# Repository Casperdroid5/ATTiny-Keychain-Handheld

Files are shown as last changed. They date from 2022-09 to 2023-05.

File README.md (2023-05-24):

# ATTiny Keychain Handheld

The ATTiny Keychain Handheld is an open-source project aimed at creating a compact and portable handheld device using the ATTiny microcontroller. This project provides a platform for hobbyists and electronics enthusiasts to build their own handheld device for various purposes such as gaming, basic applications, or custom projects.

## Features

- Compact and portable design
- ATTiny microcontroller
- OLED display
- User input
- Programmable
- Open-source

## Usage

To use the ATTiny Keychain Handheld, follow these steps:

1. Clone or download the project repository from [GitHub](https://github.com/Casperdroid5/ATTiny-Keychain-Handheld).
2. Gather the necessary components and tools required for building the handheld device.
3. Assemble the device following the step-by-step instructions provided in the documentation.
4. Upload the firmware code to the ATTiny microcontroller using the provided programming instructions.
5. Customize the device as desired by modifying the firmware code or the design files for the enclosure.

## Documentation

Detailed documentation and guides on how to build and customize the handheld device can be found in the [Documentation](https://github.com/Casperdroid5/ATTiny-Keychain-Handheld/tree/main/Documentation) directory of the project repository. The documentation includes component lists, PCB design and circuit diagrams.

## Contributing

Contributions to the ATTiny Keychain Handheld project are welcome. If you find any issues, have suggestions for improvements, or want to contribute new features, please refer to the [Contributing](https://github.com/Casperdroid5/ATTiny-Keychain-Handheld/tree/main/Contributing) directory in the project repository.

## License

The ATTiny Keychain Handheld project is released under the [MIT License](https://github.com/Casperdroid5/ATTiny-Keychain-Handheld/blob/main/LICENSE).

## Conclusion

The ATTiny Keychain Handheld project offers an exciting opportunity for electronics enthusiasts and hobbyists to build their own portable handheld device. With its compact design, ATTiny microcontroller, and open-source nature, the project provides a versatile platform for creating various applications and games. Whether you are a beginner or an experienced developer, this project encourages exploration and customization.

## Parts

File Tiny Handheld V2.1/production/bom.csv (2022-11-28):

Designator | Footprint | Quantity | Value | LCSC Part #
5V | TestPoint_Pad_1.0x1.0mm | 1 | 5V
BT1 | BatteryHolder_Keystone_3002_1x2032 | 1 | Battery_Cell
C1 | C_1206_3216Metric_Pad1.33x1.80mm_HandSolder | 1 | 1uF 16V
C2 | C_1206_3216Metric_Pad1.33x1.80mm_HandSolder | 1 | 1uF
C3 | C_1206_3216Metric_Pad1.33x1.80mm_HandSolder | 1 | 47uF
C4 | C_1206_3216Metric_Pad1.33x1.80mm_HandSolder | 1 | 100nF
C6 | C_1206_3216Metric_Pad1.33x1.80mm_HandSolder | 1 | 2.2uF 16V
D1, D2 | LED_1206_3216Metric_Pad1.42x1.75mm_HandSolder | 2 | LED
GND | TestPoint_Pad_1.0x1.0mm | 1 | GND
H1 | MountingHole_3.2mm_M3 | 1 | MountingHole
IC1 | SOT-23-6_Handsoldering | 1 | BQ21040DBVR
J1 | PinSocket_1x06_P2.54mm_Vertical | 1 | VDisplay/prog1
J2 | PinSocket_1x06_P2.54mm_Vertical | 1 | HDisplay/prog
J3 | TYPE-C-31-M-17_handsolder | 1 | USB_C_Receptacle_USB2.0
JP1, JP2, JP3 | SolderJumper-3_P1.3mm_Open_RoundedPad1.0x1.5mm_NumberLabels | 3 | SolderJumper_3_Bridged123
LS1 | XDCR_KSSGK4B16-20 | 1 | KSSGK4B16-20
R1, R4 | R_1206_3216Metric_Pad1.30x1.75mm_HandSolder | 2 | 88k
R10 | R_1206_3216Metric_Pad1.30x1.75mm_HandSolder | 1 | 10k
R11, R12 | R_1206_3216Metric_Pad1.30x1.75mm_HandSolder | 2 | 4k7
R13, R14 | R_1206_3216Metric_Pad1.30x1.75mm_HandSolder | 2 | 5k1
R15 | R_1206_3216Metric_Pad1.30x1.75mm_HandSolder | 1 | 10k NTC
R16, R8 | R_1206_3216Metric_Pad1.30x1.75mm_HandSolder | 2 | 470
R2, R6 | R_1206_3216Metric_Pad1.30x1.75mm_HandSolder | 2 | 22k
R3, R5, R7 | R_1206_3216Metric_Pad1.30x1.75mm_HandSolder | 3 | 33k
R9 | R_1206_3216Metric_Pad1.30x1.75mm_HandSolder | 1 | 11k
S1 | SW_SPST_TL3305B | 1 | MOMENTARY-SWITCH-SPST-2-SMD-5.2MM
S2 | 5 way button (joystick) | 1 | JOYSTICK_MINI
S3, S4 | SW_JS202011SCQN | 2 | JS202011SCQN
U1 | DIP781W56P254L950H533Q8N | 1 | ATtiny85-20P
U2 | SOIC-8W_5.3x5.3mm_P1.27mm | 1 | ATtiny85-20S
en-charge | SolderJumper-2_P1.3mm_Open_RoundedPad1.0x1.5mm | 1 | Jumper_2_Open

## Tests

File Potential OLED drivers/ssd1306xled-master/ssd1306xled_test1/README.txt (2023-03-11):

TESTING - This is a testing project for the library.

To build the project, type:
	$ make

To upload the binary into the microcontroller, type:
	$ make program

Alternatively, to upload the binary, type:
	$ avrdude -c usbasp -p t85 -U flash:w:"main.hex":a

To clean up files left out from previous builds, type:
   $ make clean

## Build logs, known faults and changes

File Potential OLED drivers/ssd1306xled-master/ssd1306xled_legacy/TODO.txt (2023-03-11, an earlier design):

TODO

2019-04-27 (nb)

- Fix library (probably the init seq.) to work with SSD1315 also. (DONE)

2018-12-26 (nb)

- Move font .h files to the app space, i.e. not in the library folder.
- Separate SSD1306xLEDfx library for the more complex functions such as drawings.	(DONE)
- Separate SSD1306xLEDtx library for the more complex functions such as printing chars and strings.	(DONE)
- Extract the I2C function as a separate library.
- Update makefile to the newer style, like it is in the other projects.	(DONE)
- Use the NUM2STR library from TinyAVRLib project.	(DONE)
- Remove the "_cn" modules - no longer used and developed.	(DONE)

2016, 2017

- Print decimal numbers.	(DONE)
- Short vertical line.
- Implement power saving modes for the display.

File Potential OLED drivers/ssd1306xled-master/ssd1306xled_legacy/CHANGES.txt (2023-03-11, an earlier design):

CHANGES

2019-04-27 (nb)

Code optimizations in ssd1306xledtx for speed and size.

Testing scripts updated and tested.

Updated ssd1306_init_sequence, fixes and more, compatibility with SSD1315.

2019-02-10 (nb)

Testing scripts updated and tested.

Some refactoring/renaming, minor fixes, optimizations, removed unused functions.
- Some refactoring (renaming). Minor fixes.
- Code optimizations for size and speed.
- Removed unused functions.

2019-02-03 (nb)

Added "extern" functions where needed.

FIX: used wrong function - *_start/stop instead of *data_start/stop.

2019-01-27 (nb)

Minor source code reformatting.

Some functions moved to the new internal library - I2CSW - I2C Simple Writer,, other renamed. Testing scripts updated.

2018-12-26 (nb)

Functions from the ssd1306xledtx module now have the ssd1306tx_ prefix, names changed a little. Implemented ssd1306tx_init function.

Moved to a new ssd1306xledtx module, function to work with images.

Moved to a new ssd1306xledfx module, function to work with text.

Updated testing scripts. Source code maintenance. Updated TODO list.

Removed unused modules - local copy of "num2str", "ssd1306xled_cn" and "ssd1306xled_test_cn".

Source code maintenance. Changes in the texts.

2018-05-24 (nb)

Source code reorganizing, reformatting. Removed unused. Some optimizations.

Added new ssd1306xled_text1 module for testing text output.

Improved fonts handling. Moved ssd1306_string_font8x16xy to main library.

Added new ssd1306xled_text2 testing script.

Removed unused ssd1306xled8x16 files.

Switched to using the num2str from the tinyavrlib.

Added new ssd1306xled_nums1 testing script.

Added new ssd1306xled_imgs1 testing script.

Added new ssd1306_byte function that writes one vertical byte on the screen.

Updated ssd1306xled_test1 script to show simple tests.

Fixed bug in the ssd1306_byte function.

2018-05-23 (nb)

Added more comments in the source code.

Remove unused cpufreq.h file. More comments in the source code. Updated copyright and related info.

Improved Makefile. More comments in the source code. Updated copyright and related info.

2016-05-01 (nb)

Added support for, and tested to work with, 8 MHz CPU clock. Other small fixes.

- Added support for, and tested to work with, 8 MHz CPU clock. Using CPUFREQ.
- Replaced "while (1)" with "for (;;)".

2016-05-01 (nb)

Renamed function names - for clarity, added new. Improved testing script.

- Refactoring: renamed ssd1306_fillp to ssd1306_fill2; ssd1306_char_f8x16 to ssd1306_string_font8x16xy.
- Added new: ssd1306_fill4 function; ssd1306_clear macro.
- Improved testing script.

2016-05-01 (nb)

Renamed ssd1306xled_test to ssd1306xled_test1.

2016-05-01 (nb)

Fixed Makefile. Other small changes.

- Fixed Makefile.
- Updated texts, fixed typos.

2016-04-29 (nb)

Updated to the latest NUM2STR. Other small updated and fixes.

- Updated to the latest NUM2STR.
- Removed old unused code.
- Updated text files. Fixed typos.

2015-09-26 (nb)

Added new functions and definitions. Updated testing app. Other small fixes.

- Added macro definitions for new ssd1306_char, ssd1306_string, ssd1306_numdec, ssd1306_numdecp functions.
- Added new ssd1306_fillp, ssd1306_fill functions.
- Removed old and unused code.
- Updated and improved testing app.
- Fixes in texts and comments.

2015-01-17 (nb)

Added support for printing decimal numbers.

- Added support for printing decimal numbers with the "num2str" library. New functions: ssd1306_numdec_font6x8, ssd1306_numdecp_font6x8.
- Minor updates in the text files.

2015-01-13 (nb)

Updated README file - added folders and files layout.

2015-01-12 (nb)

Added MIT License info, added LICENSE.txt file. Added licensing info to the source code file.

2015-01-12 (nb)

Updated RESEARCH and TODO files.

2015-01-10 (nb)

Fixed and improved initialization. New and improved printing of text. Updated texts.

- Fixed initialization commands.
- Implemented ssd1306_init more efficiently.
- New functions ssd1306_send_command_start, ssd1306_send_command_stop.
- Improved ssd1306_setpos, more efficient.
- Reimplemented function ssd1306_char_f6x8 as improved ssd1306_char_font6x8 printing single characters only, added new ssd1306_string_font6x8 for printing strings.
- The font8x16 functions and data moved to another file until properly implemented.
- Added to the Make file ssd1306xled8x16 file.
- Updated testing text displayed on the screen.

2015-01-10 (nb)

Changed default pins for display, now PB0=SCL and PB1=SDA. Source code reformatting, improvements, edited comments.

- Changed default pins for connecting to the display for consistency with the built-in TWI interface, they are now PB0=SCL and PB1=SDA.
- Source code, removed redundant initializations of variables.
- Source code reformatting, edited comments.

2015-01-10 (nb)

Fixed some warnings, variables renamed. The font16x16/Chinese stuff moved to other folders.

- Font variable ssd1306xled_font8X16 renamed to ssd1306xled_font8x16 for consistency. TODO: rename "ssd1306xled_font8x16" file as well.
- Fixed ssd1306_draw_bmp prototype: added "const" to bitmap so it won't generate warning.
- Files related to font 16x16 (Chinese) moved to different folders: font16x16cn.h.
- Functions and other code related to font 16x16 (Chinese) moved to different folders.
- Source code reformatting, edited comments.

2014-10-26 (gs)

Make project compile on gcc-avr - turn static images to consts, and rename include of font16x16cn.h

2014-08-13 (nb)

More files added to the repository.

2014-08-11 (nb)

Files added to the repository.

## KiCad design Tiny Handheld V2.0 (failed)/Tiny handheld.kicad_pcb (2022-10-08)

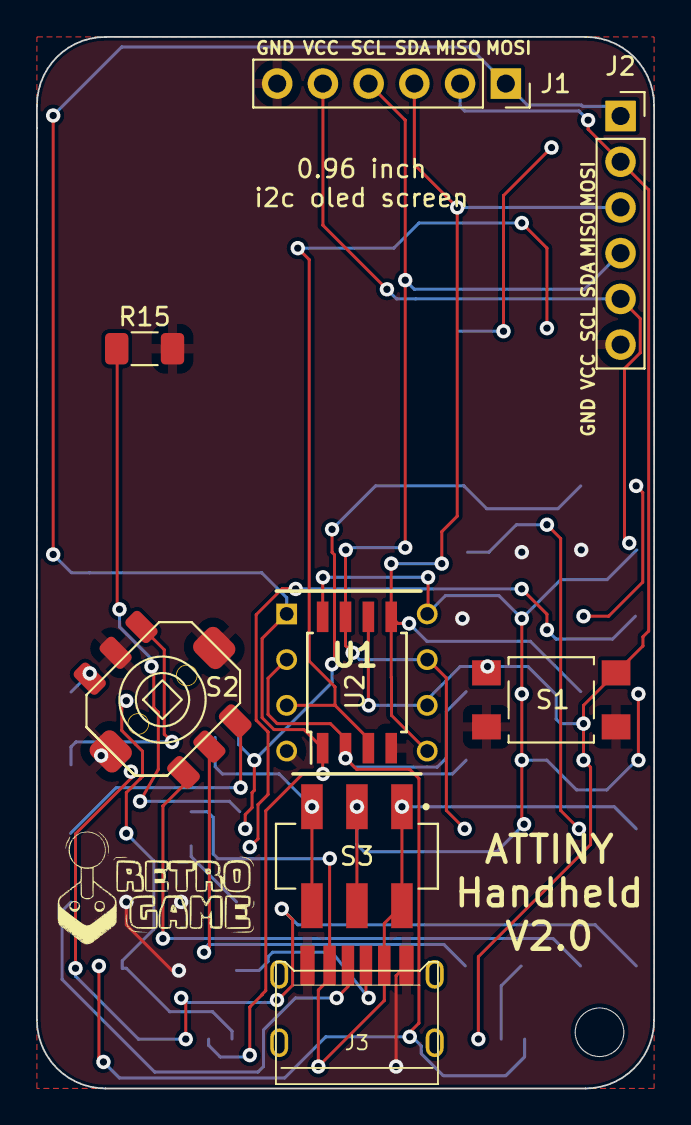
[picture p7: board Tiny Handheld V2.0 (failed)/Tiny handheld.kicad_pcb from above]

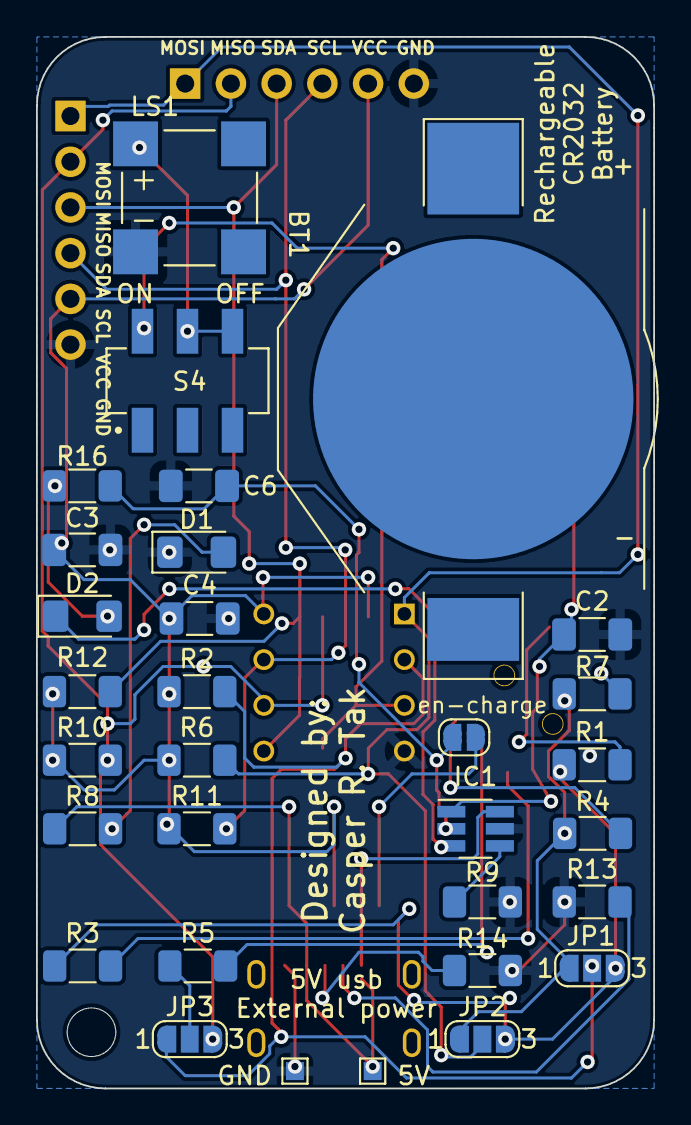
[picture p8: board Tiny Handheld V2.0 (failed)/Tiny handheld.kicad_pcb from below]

Board: 2 copper layers, 34.3 x 58.4 mm, 40 parts (31 on the bottom side), 27 nets.

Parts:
5V: 5V; TestPoint_Pad_1.0x1.0mm
BT1: BATTERY-6.8MM_SMD; BatteryHolder_Keystone_3002_1x2032
C2: 1uF; C_1206_3216Metric_Pad1.33x1.80mm_HandSolder
C3: 47uF; C_1206_3216Metric_Pad1.33x1.80mm_HandSolder
C4: 100nF; C_1206_3216Metric_Pad1.33x1.80mm_HandSolder
C6: 2.2uF 16V; C_1206_3216Metric_Pad1.33x1.80mm_HandSolder
D1, D2: LED; LED_1206_3216Metric_Pad1.42x1.75mm_HandSolder
GND: GND; TestPoint_Pad_1.0x1.0mm
IC1: BQ21040DBVR; SOT-23-6_Handsoldering
J1: VDisplay/prog1; PinSocket_1x06_P2.54mm_Vertical
J2: HDisplay/prog; PinSocket_1x06_P2.54mm_Vertical
J3: USB_C_Receptacle_USB2.0; TYPE-C-31-M-17_handsolder
JP1, JP2, JP3: SolderJumper_3_Bridged123; SolderJumper-3_P1.3mm_Open_RoundedPad1.0x1.5mm_NumberLabels
LS1: KSSGK4B16-20; XDCR_KSSGK4B16-20
R1, R4: 88k; R_1206_3216Metric_Pad1.30x1.75mm_HandSolder
R2, R6: 22k; R_1206_3216Metric_Pad1.30x1.75mm_HandSolder
R3, R5, R7: 33k; R_1206_3216Metric_Pad1.30x1.75mm_HandSolder
R8, R16: 470; R_1206_3216Metric_Pad1.30x1.75mm_HandSolder
R9: 11k; R_1206_3216Metric_Pad1.30x1.75mm_HandSolder
R10: 10k; R_1206_3216Metric_Pad1.30x1.75mm_HandSolder
R11, R12: 4k7; R_1206_3216Metric_Pad1.30x1.75mm_HandSolder
R13, R14: 5k1; R_1206_3216Metric_Pad1.30x1.75mm_HandSolder
R15: 10k NTC; R_1206_3216Metric_Pad1.30x1.75mm_HandSolder
S1: MOMENTARY-SWITCH-SPST-2-SMD-5.2MM; SW_SPST_TL3305B
S2: JOYSTICK_MINI; 5 way button (joystick)
S3, S4: JS202011SCQN; SW_JS202011SCQN
U1: ATtiny85-20P; DIP781W56P254L950H533Q8N
U2: ATtiny85-20S; SOIC-8W_5.3x5.3mm_P1.27mm
en-charge: Jumper_2_Open; SolderJumper-2_P1.3mm_Open_RoundedPad1.0x1.5mm

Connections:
BatOut: S3.3, S3.6, en-charge.2 (B)
ExtVCC: 5V.1, IC1.6 (VIN), J3.A9 (VBUS), J3.B9 (VBUS), R8.1, S3.1, S3.4
GND: C2.2, C3.2, C4.2, C6.2, D1.1 (K), GND.1, IC1.5 (GND), J1.6, J2.6, J3.A12 (GND), J3.B12 (GND), LS1.N, R9.2, R13.1, R14.1, R15.2, S1.1, S1.2, S2.7, S2.8, S2.GND, U1.4 (GND), U2.4 (GND)
unnamed: C2.1, IC1.1 (TS), R15.1
unnamed: C6.1, IC1.2 (OUT), R16.1, en-charge.1 (A)
unnamed: D1.2 (A), R8.2
unnamed: D2.1 (K), IC1.3 (~CHG)
unnamed: D2.2 (A), R16.2
unnamed: IC1.4 (ISET), R9.1
unnamed: J3.A5 (CC1), R13.2
unnamed: J3.B5 (CC2), R14.2
unnamed: JP1.1 (A), JP2.1 (A), R4.1, R7.1
unnamed: JP1.3 (B), JP2.3 (B), R1.1, R3.1
unnamed: JP3.2 (C), R5.1
unnamed: LS1.P, S4.5, S4.6
unnamed: R1.2, S2.D (DOWN)
unnamed: R3.2, S2.A (UP)
unnamed: R4.2, S2.C (LEFT)
unnamed: R5.2, S2.CTR (CENT)
unnamed: R7.2, S2.B (RIGHT)
PB0/SDA/MOSI: J1.3, J2.3, R12.2, U1.5 (AREF/PB0), U2.5 (AREF/PB0)
PB1/MISO: J1.2, J2.2, JP3.3 (B), R10.2, S1.3, S1.4, U1.6 (PB1), U2.6 (PB1)
PB2/SCL/SCK: J1.4, J2.4, R11.2, U1.7 (PB2), U2.7 (PB2)
PB3: JP1.2 (C), JP3.1 (A), R2.2, U1.2 (XTAL1/PB3), U2.2 (XTAL1/PB3)
PB4: S4.4, U1.3 (XTAL2/PB4), U2.3 (XTAL2/PB4)
PB5/RES: J1.1, J2.1, JP2.2 (C), R6.2, U1.1 (~RESET/PB5), U2.1 (~RESET/PB5)
VCC: C3.1, C4.1, J1.5, J2.5, R2.1, R6.1, R10.1, R11.1, R12.1, S3.2, S3.5, U1.8 (VCC), U2.8 (VCC)

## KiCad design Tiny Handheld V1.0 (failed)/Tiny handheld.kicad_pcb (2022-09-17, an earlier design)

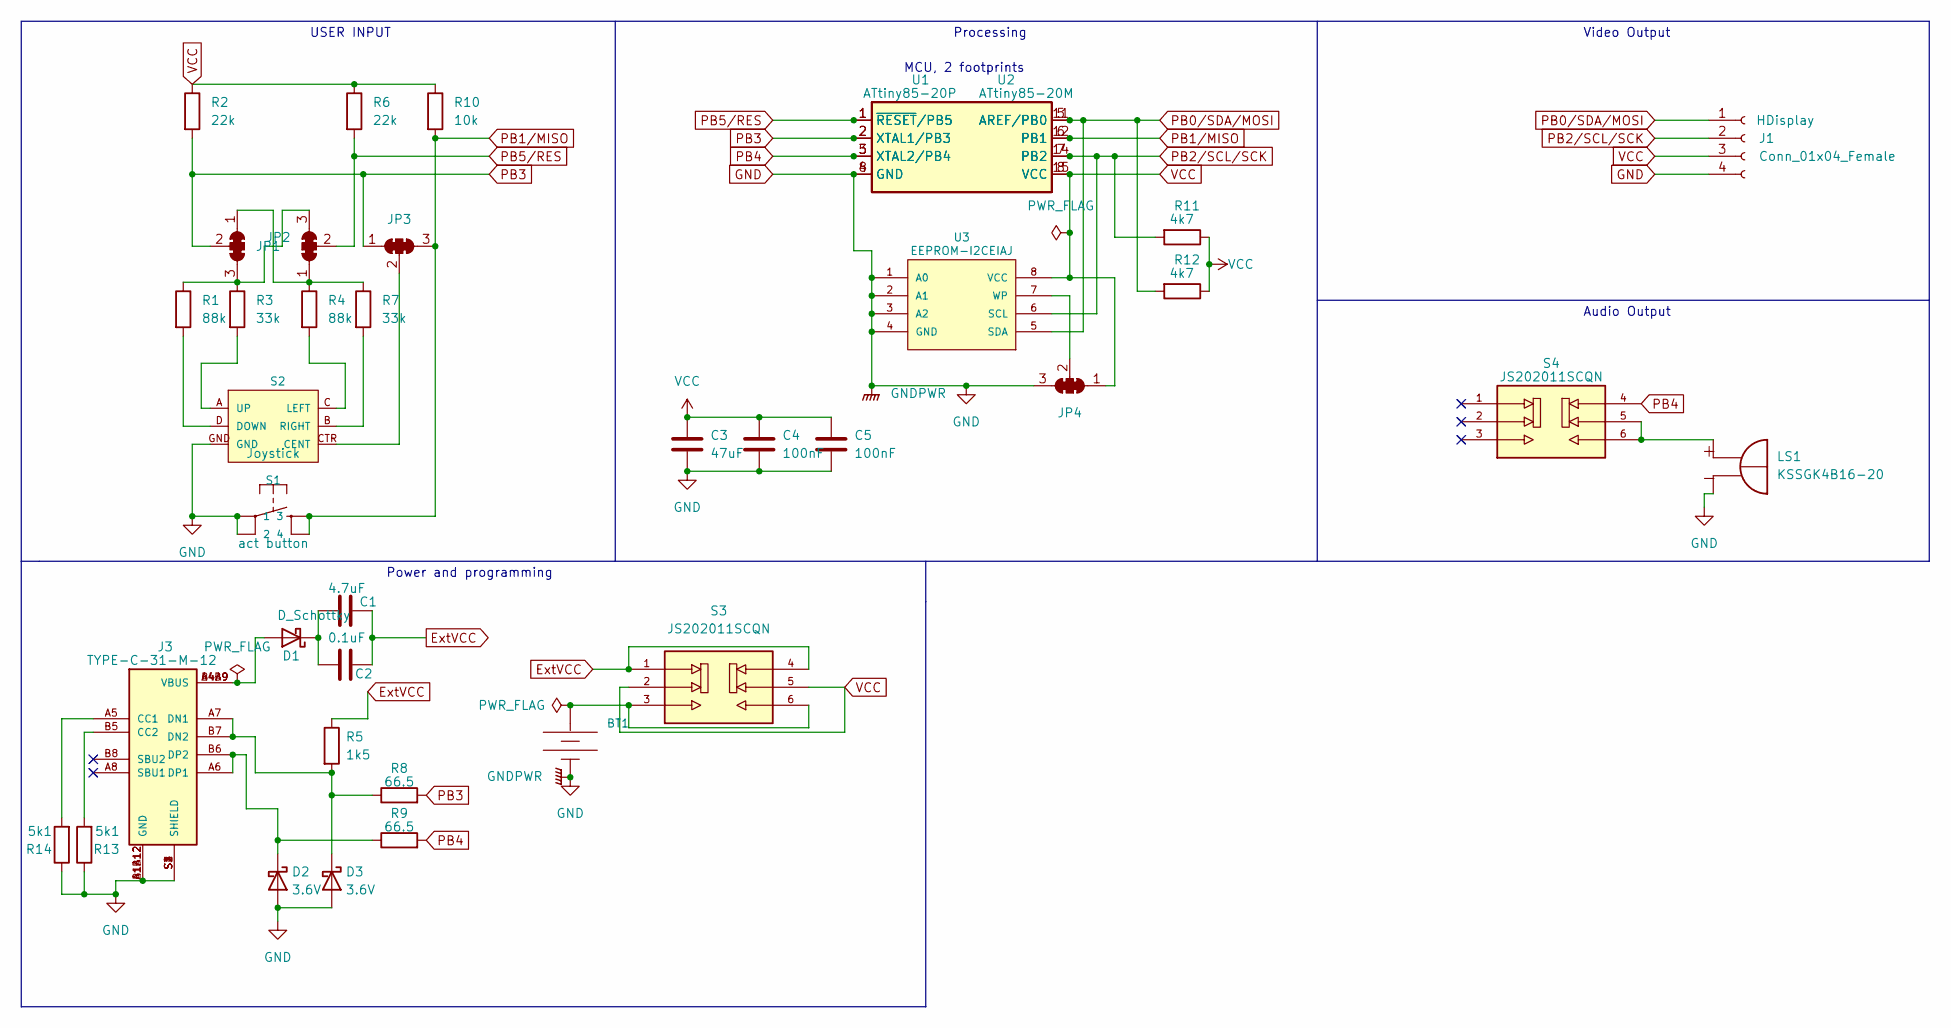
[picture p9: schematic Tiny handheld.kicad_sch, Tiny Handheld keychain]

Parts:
BT1: BATTERY-6.8MM_SMD; BAT_BU2032-1
C1: 4.7uF; C_1206_3216Metric_Pad1.33x1.80mm_HandSolder
C2: 0.1uF; C_1206_3216Metric_Pad1.33x1.80mm_HandSolder
C3: 47uF; C_1206_3216Metric_Pad1.33x1.80mm_HandSolder
C4, C5: 100nF; C_1206_3216Metric_Pad1.33x1.80mm_HandSolder
D1: D_Schottky; D_1210_3225Metric_Pad1.42x2.65mm_HandSolder
D2, D3: 3.6V; D_1210_3225Metric_Pad1.42x2.65mm_HandSolder
J1: Conn_01x04_Female; PinHeader_1x04_P2.54mm_Vertical
J3: TYPE-C-31-M-12; HRO_TYPE-C-31-M-12; PARTREV A
JP1, JP2, JP3, JP4: SolderJumper_3_Bridged123; SolderJumper-3_P1.3mm_Open_RoundedPad1.0x1.5mm_NumberLabels
LS1: KSSGK4B16-20; XDCR_KSSGK4B16-20; PARTREV 1.1
R1, R4: 88k; R_1206_3216Metric_Pad1.30x1.75mm_HandSolder
R2, R6: 22k; R_1206_3216Metric_Pad1.30x1.75mm_HandSolder
R3, R7: 33k; R_1206_3216Metric_Pad1.30x1.75mm_HandSolder
R5: 1k5; R_1206_3216Metric_Pad1.30x1.75mm_HandSolder
R8, R9: 66.5; R_1206_3216Metric_Pad1.30x1.75mm_HandSolder
R10: 10k; R_1206_3216Metric_Pad1.30x1.75mm_HandSolder
R11, R12: 4k7; R_1206_3216Metric_Pad1.30x1.75mm_HandSolder
R13, R14: 5k1; R_1206_3216Metric_Pad1.30x1.75mm_HandSolder
S1: MOMENTARY-SWITCH-SPST-2-SMD-5.2MM; SW_SPST_TL3305B
S2: JOYSTICK_MINI; 5 way button (joystick)
S3, S4: JS202011SCQN; SW_JS202011SCQN; PARTREV 26 May 22
U1: ATtiny85-20P; DIP-8_W7.62mm
U2: ATtiny85-20M; QFN50P400X400X80-21N
U3: EEPROM-I2CEIAJ; SOIC-8_3.9x4.9mm_P1.27mm

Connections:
ExtVCC: C1.1, C2.1, R5.1, S3.1, S3.4
GND: BT1.-, C3.2, C4.2, C5.2, D2.2 (A), D3.2 (A), J1.4, J3.A1B12 (GND), J3.B1A12 (GND), J3.S1 (SHIELD), J3.S2 (SHIELD), J3.S3 (SHIELD), J3.S4 (SHIELD), JP4.3 (B), LS1.N, R13.1, R14.1, S1.1, S1.2, S2.GND, U1.4 (GND), U2.8 (GND), U2.21 (GND), U3.1 (A0), U3.2 (A1), U3.3 (A2), U3.4 (GND)
unnamed: C1.2, C2.2, D1.1 (K)
unnamed: D1.2 (A), J3.A4B9 (VBUS), J3.B4A9 (VBUS)
unnamed: D2.1 (K), J3.A6 (DP1), J3.B6 (DP2), R9.1
unnamed: D3.1 (K), J3.A7 (DN1), J3.B7 (DN2), R5.2, R8.1
unnamed: J3.A5 (CC1), R14.2
unnamed: J3.B5 (CC2), R13.2
unnamed: JP1.1 (A), JP2.1 (A), R4.1, R7.1
unnamed: JP1.3 (B), JP2.3 (B), R1.1, R3.1
unnamed: JP3.2 (C), S2.CTR (CENT)
unnamed: JP4.2 (C), U3.7 (WP)
unnamed: LS1.P, S4.5, S4.6
unnamed: R1.2, S2.D (DOWN)
unnamed: R3.2, S2.A (UP)
unnamed: R4.2, S2.C (LEFT)
unnamed: R7.2, S2.B (RIGHT)
PB0/SDA/MOSI: J1.1, R12.2, U1.5 (AREF/PB0), U2.11 (AREF/PB0), U3.5 (SDA)
PB1/MISO: JP3.3 (B), R10.2, S1.3, S1.4, U1.6 (PB1), U2.12 (PB1)
PB2/SCL/SCK: J1.2, R11.2, U1.7 (PB2), U2.14 (PB2), U3.6 (SCL)
PB3: JP1.2 (C), JP3.1 (A), R2.2, R8.2, U1.2 (XTAL1/PB3), U2.2 (XTAL1/PB3)
PB4: R9.2, S4.4, U1.3 (XTAL2/PB4), U2.5 (XTAL2/PB4)
PB5/RES: JP2.2 (C), R6.2, U1.1 (~RESET/PB5), U2.1 (~RESET/PB5)

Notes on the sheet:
MCU, 2 footprints
Audio Output
Power and programming
USER INPUT
Video Output
Processing

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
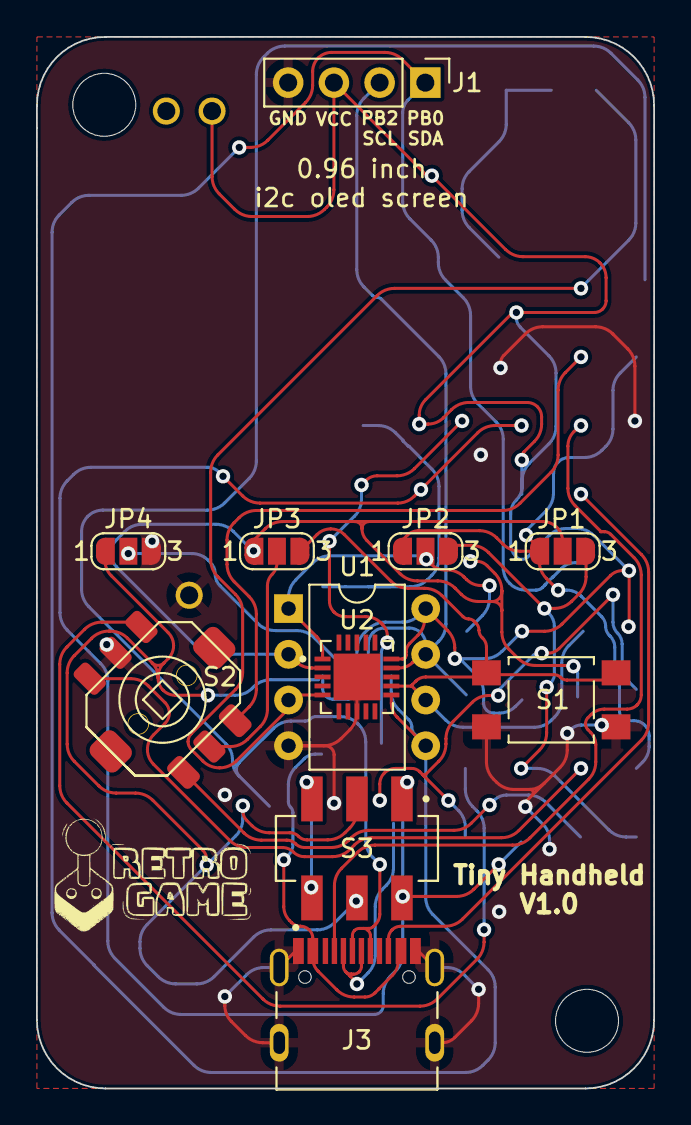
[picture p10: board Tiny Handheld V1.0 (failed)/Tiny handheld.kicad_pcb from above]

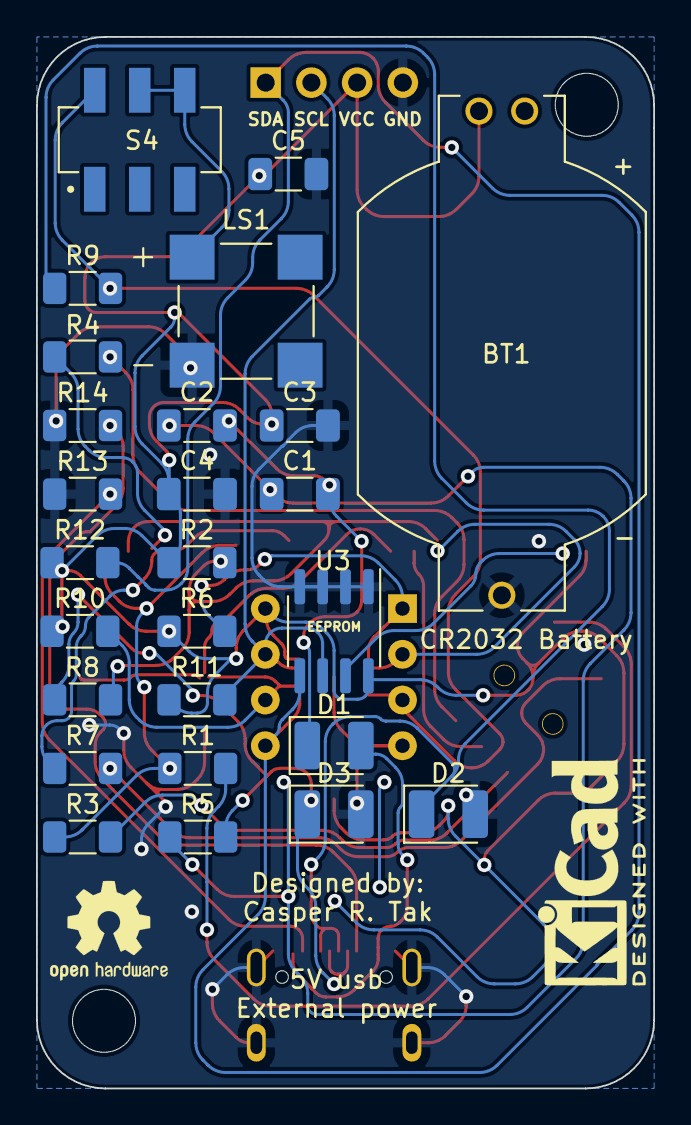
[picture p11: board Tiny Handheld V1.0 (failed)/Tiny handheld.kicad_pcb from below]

Board: 2 copper layers, 34.3 x 58.4 mm, 37 parts (26 on the bottom side), 25 nets.

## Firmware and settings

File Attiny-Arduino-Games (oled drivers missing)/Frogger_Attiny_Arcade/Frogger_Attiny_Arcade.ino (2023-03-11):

/*  2015 / 2016 / 2017
 *  Frogger game by Andy Jackson - Twitter @andyhighnumber
 *  
 *  Special thanks to @senkunmusahi, who created the artwork bitmaps in the game using https://www.riyas.org/2013/12/online-led-matrix-font-generator-with.html
 *  
 *  Inspired by http://webboggles.com/ and includes some code from the #AttinyArcade games on that site
 *  The code that does not fall under the licenses of sources listed below can be used non commercially with attribution.
 *  This software is supplied without warranty of any kind.
 *  
 *  Controls:
 *  On the standard AttinyArcade:
 *  LEFT and RIGHT buttons move the frog across 
 *  BOTH BOTTONS TOGETHER move the frog forwards
 *  
 *  HIGHLY RECOMMENDED:
 *  On custom hardware (see schematic in folder where you found this file) there is an additional button to move frog forward  
 *  
 *  Also, from standby....
 *  Press and hold left button to turn sound on and off
 *  Press and hold left button with the right button held to reset high score
 * 
 *  This sketch is using the screen control and font functions written by Neven Boyanov for the http://tinusaur.wordpress.com/ project
 *  Source code and font files available at: https://bitbucket.org/tinusaur/ssd1306xled
 *  **Note that this highly size-optimised version requires modified library functions (which are in this source code file) 
 *  and a modified font header
 * 
 *  Sleep code is based on this blog post by Matthew Little:
 *  http://www.re-innovation.co.uk/web12/index.php/en/blog-75/306-sleep-modes-on-attiny85
*/
#include <EEPROM.h>
#include "font6x8AJ2.h"
#include <avr/pgmspace.h>
#include <avr/sleep.h>
#include <avr/interrupt.h> // needed for the additional interrupt

// Uncomment this #define to make the logs smaller (/thinner)
//#define SMALLLOGS

// Make click delay an even number - it gets halved and then used in an integer comparison
#define CLICKDELAY 120 

// The basline speed - higher number is slower
#define MOVEBASE 1000 

#define DIGITAL_WRITE_HIGH(PORT) PORTB |= (1 << PORT)
#define DIGITAL_WRITE_LOW(PORT) PORTB &= ~(1 << PORT)

// Routines to set and clear bits (used in the sleep code)
#define cbi(sfr, bit) (_SFR_BYTE(sfr) &= ~_BV(bit))
#define sbi(sfr, bit) (_SFR_BYTE(sfr) |= _BV(bit))

// Defines for OLED output
#define SSD1306XLED_H
#define SSD1306_SCL   PORTB4  // SCL, Pin 4 on SSD1306 Board - for webbogles board
#define SSD1306_SDA   PORTB3  // SDA, Pin 3 on SSD1306 Board - for webbogles board
#define SSD1306_SA    0x78  // Slave address

// Function prototypes

// Drawing functions - adapted from those at https://bitbucket.org/tinusaur/ssd1306xled
void ssd1306_init(void);
void ssd1306_xfer_start(void);
void ssd1306_xfer_stop(void);
void ssd1306_send_byte(uint8_t byte);
void ssd1306_send_command(uint8_t command);
void ssd1306_send_data_start(void);
void ssd1306_send_data_stop(void);
void ssd1306_setpos(uint8_t x, uint8_t y);
void ssd1306_fillscreen(uint8_t fill_Data);
void ssd1306_char_f6x8(uint8_t x, uint8_t y, const char ch[]);
void ssd1306_draw_bmp(uint8_t x0, uint8_t y0, uint8_t x1, uint8_t y1, uint8_t bitmap[]);

// Custom draw functions - allow for extra functionality like inverse display
void sendBlock(byte, bool);
void sendByte(byte, bool);

// Other generic functions for games (both originated in code from webboggles.com and the sleep code is by Matthew Little - see above)
void beep(int,int);
void system_sleep(void);
void doNumber (int,int,int);

// Game functions
void playFrogger(void);
void levelUp(int);
void moveBlocks(void);
void initScreen(void);
void drawDocks(void);
void drawLives(void);
void displayTitle(void);
void resetDock(byte);
void checkCollision(void);

// Global variables - yes I know all these global vars is a lazy way to code but it makes it easier to prevent stack overflows when you're working with 512 bytes! 
// Most of these are initialised in the main game function (playFrogger())
int watchDog;             // Counts drawing cycles so I can shut the game down if there's inactivity - battery saver!
boolean stopAnimate;      // this is set to 1 when a collision is detected
int lives;                // Lives in the game - this can go negative to end the game, which is why it's a signed variable  
bool frogDocks[5];        // Tracks which frog docks are full (at the top of the screen)
bool flipFlop;            // Used in routines that flip-flop between two states (left and right)
bool flipFlopShift;       // Same as previous one
byte frogColumn;          // Column location of frog (there are 16 altogether)
byte frogRow;             // Row locaiton of frog (there are 8, but 0 is the frog docks at the top and 7 is the start row)
byte frogLeftLimit;       // Left limit of frog travel on start row (changes as digits in score increases)
byte frogRightLimit;      // Right limit of frog travel on start row (changes as lives decrease as there's then more space)
byte level;               // Level - starts at 1
byte blockShiftL;         // Number of pixels to shift the left-going rows by
byte blockShiftR;         // Number of pixels to shift the right-going rows by
int interimStep;          // Used as timer for incremental movements
int moveDelay;            // How long to wait until the next movement of logs etc - changes as levels increase to make the game go faster
int dockedFrogs;          // How many frogs are in the docks at the top
unsigned long clickBase;  // Timer for debounce
boolean clickLock;        // For debounce routine
int score;                // Obvious I hope
int topScore;             // High score
boolean newHigh;          // Is there a new high score?
boolean mute = 0;         // Mute the speaker
byte grid[6][16];         // Grid for items like logs, crocs, cars and lorries
byte frogMode;            // Represents the frog direction 
bool moveForward=0;       // Captures when the 'forward' button is pressed
bool moveLeft=0;          // Captures when the 'left' button is pressed
bool moveRight=0;         // Captures when the 'right' button is pressed

// Bitmaps created by @senkunmusahi using https://www.riyas.org/2013/12/online-led-matrix-font-generator-with.html
static const byte  bitmaps[15][8] PROGMEM = {
// Frogs
  {0x83, 0xDC, 0x7A, 0x3F, 0x3F, 0x7A, 0xDC, 0x83},
  {0x99, 0xBD, 0xDB, 0x7E, 0x7E, 0x3C, 0xE7, 0x81},
  {0x81, 0xE7, 0x3C, 0x7E, 0x7E, 0xDB, 0xBD, 0x99},

#ifdef SMALLLOGS
// Small logs
  {0x1C, 0x22, 0x41, 0x55, 0x55, 0x51, 0x43, 0x61},
  {0x69, 0x6B, 0x43, 0x61, 0x45, 0x45, 0x61, 0x65},
  {0x45, 0x55, 0x41, 0x5D, 0x63, 0x5D, 0x22, 0x1C},
#else
// Bigger logs
  {0x3C, 0x7E, 0xD7, 0xB5, 0xAD, 0xBF, 0xFF, 0xED}, 
  {0xAD, 0xAD, 0xFF, 0xB7, 0xF5, 0xBF, 0xB7, 0xAD}, 
  {0xED, 0xBD, 0xC3, 0xBD, 0xA5, 0xBD, 0x42, 0x3C},  
#endif

// Trucks
  {0x00, 0x7F, 0x41, 0x55, 0x55, 0x55, 0x55, 0x55},
  {0x55, 0x55, 0x55, 0x55, 0x55, 0x55, 0x55, 0x55}, 
  {0x41, 0x7F, 0x22, 0x7F, 0x7F, 0x63, 0x22, 0x1C},

// Crocs
  {0x41, 0x63, 0x46, 0x6E, 0x7C, 0x7E, 0x7A, 0x3E},
  {0xBC, 0xFE, 0x7E, 0x3E, 0xBE, 0xBE, 0xFC, 0x7C},  
  {0x78, 0x38, 0x38, 0x38, 0x70, 0x60, 0x60, 0x40},

// Cars
  {0x00, 0x1C, 0x22, 0x63, 0x7F, 0x7F, 0x22, 0x22},
  {0x22, 0x3E, 0x3E, 0x7F, 0x63, 0x63, 0x22, 0x1C},
  {0x22, 0x3E, 0x3E, 0x7F, 0x63, 0x63, 0x22, 0x1C}
  };

// Opening artwork created by @senkunmusahi using https://www.riyas.org/2013/12/online-led-matrix-font-generator-with.html
static const byte titleBmp[] PROGMEM = {
0x00, 0x00, 0x00, 0x00, 0x00, 0x00, 0x00, 0x00, 0x80, 0xC0, 0xF0, 0x7C, 0x06, 0x73, 0x59, 0x43,
0x06, 0x3C, 0x38, 0x30, 0x30, 0x38, 0x3E, 0x26, 0x7B, 0x59, 0x43, 0x06, 0x7C, 0xF0, 0xC0, 0x80,
0x00, 0x00, 0x00, 0x00, 0x00, 0x00, 0x00, 0x00, 0x00, 0x00, 0x00, 0x00, 0x00, 0x00, 0x78, 0xFF,
0xCF, 0x01, 0x00, 0x00, 0x30, 0x60, 0xE0, 0xC0, 0x80, 0x80, 0x80, 0x80, 0x80, 0x80, 0x80, 0xC0,
0xC0, 0x60, 0x30, 0x00, 0x00, 0x00, 0x01, 0xCF, 0xFE, 0x78, 0x00, 0x00, 0x00, 0x00, 0x00, 0x00,
0x7C, 0xFE, 0x86, 0x0E, 0x0E, 0x1C, 0x18, 0x31, 0x7F, 0xFE, 0xFC, 0x1C, 0x18, 0x38, 0x38, 0x38,
0x39, 0x39, 0x39, 0x39, 0x39, 0x39, 0x39, 0x38, 0x38, 0x38, 0x38, 0x18, 0x1C, 0xFC, 0xFE, 0x7F,
0x39, 0x18, 0x1C, 0x0E, 0x0E, 0xC6, 0xFE, 0x3C, 0x00, 0x01, 0x07, 0x0E, 0x1C, 0x38, 0x70, 0xC0,
0xC0, 0x80, 0x03, 0x07, 0xFC, 0xF8, 0x00, 0x00, 0xF0, 0xC0, 0xC0, 0xC0, 0xC0, 0xC0, 0xE0, 0xF0,
0x00, 0x00, 0xF8, 0xFC, 0x0F, 0x03, 0x80, 0xC0, 0xE0, 0x70, 0x38, 0x1C, 0x0E, 0x03, 0x01, 0x00,
0x04, 0x06, 0x0F, 0x0F, 0x06, 0x06, 0x03, 0x03, 0x03, 0x63, 0x73, 0x33, 0x3B, 0xFF, 0xFF, 0x7F,
0x3F, 0x38, 0xF0, 0xC0, 0x00, 0xF0, 0xF8, 0x3F, 0x7F, 0xFF, 0xFF, 0x3B, 0x33, 0x63, 0x63, 0x03,
0x03, 0x03, 0x06, 0x06, 0x0F, 0x0F, 0x06, 0x00, 
};

// Interrupt handlers
ISR(PCINT0_vect){ // PB0 pin button interrupt           
  if (clickLock == 0) {
    moveLeft = 1;
    clickLock = 1;
    clickBase = millis();
  }
}

void playerIncFrogger(){ // PB2 pin button interrupt
  if (clickLock == 0) {
    moveRight = 1;
    clickLock = 1;
    clickBase = millis();
  }
}

void displayTitle(void) {
  int incr = 0;
  for(int lxn = 2; lxn < 7; lxn++) {
    ssd1306_setpos(85,lxn); 
    ssd1306_send_data_start();
    for(int lxn2 = 0; lxn2 < 40; lxn2++) {
      ssd1306_send_byte(pgm_read_byte(&titleBmp[incr]));      
      incr++;
    }
    ssd1306_send_data_stop();                    
  }
}

// Arduino stuff - setup
void setup() {
  DDRB = 0b00000010;    // set PB1 as output (for the speaker)
  PCMSK = 0b00000001; // pin change mask: listen to portb bit 1
  GIMSK |= 0b00100000;  // enable PCINT interrupt 
  sei();          // enable all interrupts
}

// Arduino stuff - loop
void loop() { 
  ssd1306_init();
  ssd1306_fillscreen(0x00);

  // The lower case character set is seriously compromised because I've had to truncate the ASCII table
  // to release space for executable code.
  // There is no z in the table as this isn't used anywhere in the text here and most of the 
  // symbols are also missing for the same reason (see my hacked version of font6x8.h - font6x8AJ.h for more detail)
  ssd1306_char_f6x8(0, 2, "F R O G G E R");
  ssd1306_char_f6x8(0, 4, "andy jackson"); // see comments above !

  ssd1306_setpos(0,1); 
  for (int incr = 0; incr < 80; incr++) {
    ssd1306_send_data_start();
    ssd1306_send_byte(B00111000);
    ssd1306_send_data_stop();                    
  }
  ssd1306_setpos(0,3); 
  for (int incr = 0; incr < 80; incr++) {
    ssd1306_send_data_start();
    ssd1306_send_byte(B00011100);
    ssd1306_send_data_stop();                    
  }

  displayTitle();

  ssd1306_char_f6x8(0, 6, "inspired by");
  ssd1306_char_f6x8(0, 7, "webboggles.com");
  delay(1500);
  ssd1306_char_f6x8(0, 6, "artwork by ");
  ssd1306_char_f6x8(0, 7, "zsenkunmusashi");  // see comments above - f has been replaced by @ in the ASCII table

  long startT = millis();
  long nowT =0;
  boolean sChange = 0;

  while(digitalRead(0) == HIGH) {
    nowT = millis();
    if (nowT - startT > 2000) {
      sChange = 1;     
      if (digitalRead(2) == HIGH) {
        EEPROM.write(0,0);
        EEPROM.write(1,0);
        ssd1306_char_f6x8(8, 0, "-HIGH SCORE RESET-");  
      } else if (mute == 0) { mute = 1; ssd1306_char_f6x8(32, 0, "-- MUTE --"); } else { mute = 0; ssd1306_char_f6x8(31, 0, "- SOUND ON -");  }    
      break;
    }
    if (sChange == 1) break;
  }  
  while(digitalRead(0) == HIGH);

  if (sChange == 0) {
    delay(2000);

    ssd1306_init();
    ssd1306_fillscreen(0x00);

    playFrogger(); 

    topScore = EEPROM.read(0);
    topScore = topScore << 8;
    topScore = topScore |  EEPROM.read(1);

    newHigh = 0;
    if (score > topScore) { 
      topScore = score;
      EEPROM.write(1,score & 0xFF); 
      EEPROM.write(0,(score>>8) & 0xFF); 
      newHigh = 1;
      }

    ssd1306_fillscreen(0x00);
    ssd1306_char_f6x8(11, 1, "----------------");
    ssd1306_char_f6x8(11, 2, "G A M E  O V E R");
    ssd1306_char_f6x8(11, 3, "----------------");
    ssd1306_char_f6x8(37, 5, "SCORE:");
    doNumber(75, 5, score);
    if (!newHigh) {
      ssd1306_char_f6x8(21, 7, "HIGH SCORE:");
      doNumber(88, 7, topScore);
    }
    delay(1000);
    if (newHigh) {
      ssd1306_fillscreen(0x00);
      ssd1306_char_f6x8(10, 1, "----------------");
      ssd1306_char_f6x8(10, 3, " NEW HIGH SCORE ");
      ssd1306_char_f6x8(10, 7, "----------------");
      doNumber(50,5,topScore);
      for (int i = 700; i>200; i = i - 50){
      beep(30,i);
      }
      delay(1200);    
    } 
  }
  system_sleep();
}

void doNumber (int x, int y, int value) {
    char temp[10] = {0,0,0,0,0,0,0,0,0,0};
    itoa(value,temp,10);
    ssd1306_char_f6x8(x, y, temp);
}

void ssd1306_init(void){
  DDRB |= (1 << SSD1306_SDA); // Set port as output
  DDRB |= (1 << SSD1306_SCL); // Set port as output

  ssd1306_send_command(0xAE); // display off
  ssd1306_send_command(0x00); // Set Memory Addressing Mode
  ssd1306_send_command(0x10); // 00,Horizontal Addressing Mode;01,Vertical Addressing Mode;10,Page Addressing Mode (RESET);11,Invalid
  ssd1306_send_command(0x40); // Set Page Start Address for Page Addressing Mode,0-7
  ssd1306_send_command(0x81); // Set COM Output Scan Direction
  ssd1306_send_command(0xCF); // ---set low rowumn address
  ssd1306_send_command(0xA1); // ---set high rowumn address
  ssd1306_send_command(0xC8); // --set start line address
  ssd1306_send_command(0xA6); // --set contrast control register
  ssd1306_send_command(0xA8);
  ssd1306_send_command(0x3F); // --set segment re-map 0 to 127
  ssd1306_send_command(0xD3); // --set normal display
  ssd1306_send_command(0x00); // --set multiplex ratio(1 to 64)
  ssd1306_send_command(0xD5); // 
  ssd1306_send_command(0x80); // 0xa4,Output follows RAM content;0xa5,Output ignores RAM content
  ssd1306_send_command(0xD9); // -set display offset
  ssd1306_send_command(0xF1); // -not offset
  ssd1306_send_command(0xDA); // --set display clock divide ratio/oscillator frequency
  ssd1306_send_command(0x12); // --set divide ratio
  ssd1306_send_command(0xDB); // --set pre-charge period
  ssd1306_send_command(0x40); // 
  ssd1306_send_command(0x20); // --set com pins hardware configuration
  ssd1306_send_command(0x02);
  ssd1306_send_command(0x8D); // --set vcomh
  ssd1306_send_command(0x14); // 0x20,0.77xVcc
  ssd1306_send_command(0xA4); // --set DC-DC enable
  ssd1306_send_command(0xA6); // 
  ssd1306_send_command(0xAF); // --turn on oled panel 
}

void ssd1306_xfer_start(void){
  DIGITAL_WRITE_HIGH(SSD1306_SCL);  // Set to HIGH
  DIGITAL_WRITE_HIGH(SSD1306_SDA);  // Set to HIGH
  DIGITAL_WRITE_LOW(SSD1306_SDA);   // Set to LOW
  DIGITAL_WRITE_LOW(SSD1306_SCL);   // Set to LOW
}

void ssd1306_xfer_stop(void){
  DIGITAL_WRITE_LOW(SSD1306_SCL);   // Set to LOW
  DIGITAL_WRITE_LOW(SSD1306_SDA);   // Set to LOW
  DIGITAL_WRITE_HIGH(SSD1306_SCL);  // Set to HIGH
  DIGITAL_WRITE_HIGH(SSD1306_SDA);  // Set to HIGH
}

void ssd1306_send_byte(uint8_t byte){
  uint8_t i;
  for(i=0; i<8; i++)
  {
    if((byte << i) & 0x80)
      DIGITAL_WRITE_HIGH(SSD1306_SDA);
    else
      DIGITAL_WRITE_LOW(SSD1306_SDA);
    
    DIGITAL_WRITE_HIGH(SSD1306_SCL);
    DIGITAL_WRITE_LOW(SSD1306_SCL);
  }
  DIGITAL_WRITE_HIGH(SSD1306_SDA);
  DIGITAL_WRITE_HIGH(SSD1306_SCL);
  DIGITAL_WRITE_LOW(SSD1306_SCL);
}

void ssd1306_send_command(uint8_t command){
  ssd1306_xfer_start();
  ssd1306_send_byte(SSD1306_SA);  // Slave address, SA0=0
  ssd1306_send_byte(0x00);  // write command
  ssd1306_send_byte(command);
  ssd1306_xfer_stop();
}

void ssd1306_send_data_start(void){
  ssd1306_xfer_start();
  ssd1306_send_byte(SSD1306_SA);
  ssd1306_send_byte(0x40);  //write data
}

void ssd1306_send_data_stop(void){
  ssd1306_xfer_stop();
}

void ssd1306_setpos(uint8_t x, uint8_t y)
{
  if (y>7) return;
  ssd1306_xfer_start();
  ssd1306_send_byte(SSD1306_SA);  //Slave address,SA0=0
  ssd1306_send_byte(0x00);  //write command

  ssd1306_send_byte(0xb0+y);
  ssd1306_send_byte(((x&0xf0)>>4)|0x10); // |0x10
  ssd1306_send_byte((x&0x0f)|0x01); // |0x01

  ssd1306_xfer_stop();
}

void ssd1306_fillscreen(uint8_t fill_Data){
  uint8_t m,n;
  for(m=0;m<8;m++)
  {
    ssd1306_send_command(0xb0+m); //page0-page1
    ssd1306_send_command(0x00);   //low rowumn start address
    ssd1306_send_command(0x10);   //high rowumn start address
    ssd1306_send_data_start();
    for(n=0;n<128;n++)
    {
      ssd1306_send_byte(fill_Data);
    }
    ssd1306_send_data_stop();
  }
}

void ssd1306_char_f6x8(uint8_t x, uint8_t y, const char ch[]){
  uint8_t c,i,j=0;
  while(ch[j] != '\0')
  {
    c = ch[j] - 32;
    if (c >0) c = c - 12;
    if (c >15) c = c - 6;
    if (c>40) c=c-9;
    if(x>126)
    {
      x=0;
      y++;
    }
    ssd1306_setpos(x,y);
    ssd1306_send_data_start();
    for(i=0;i<6;i++)
    {
      ssd1306_send_byte(pgm_read_byte(&ssd1306xled_font6x8[c*6+i]));
    }
    ssd1306_send_data_stop();
    x += 6;
    j++;
  }
}

void system_sleep(void) {
  ssd1306_fillscreen(0x00);
  ssd1306_send_command(0xAE);
  cbi(ADCSRA,ADEN);                    // switch analog to digital converter off
  set_sleep_mode(SLEEP_MODE_PWR_DOWN); // sleep mode is set here
  sleep_enable();
  sleep_mode();                        // system actually sleeps here
  sleep_disable();                     // system continues execution here when watchdog timed out 
  sbi(ADCSRA,ADEN);                    // switch analog to digital converter on
  ssd1306_send_command(0xAF);
}

void beep(int bCount,int bDelay){
  if (mute) return;
  for (int i = 0; i<=bCount; i++){digitalWrite(1,HIGH);for(int i2=0; i2<bDelay; i2++){__asm__("nop\n\t");}digitalWrite(1,LOW);for(int i2=0; i2<bDelay; i2++){__asm__("nop\n\t");}}
}
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

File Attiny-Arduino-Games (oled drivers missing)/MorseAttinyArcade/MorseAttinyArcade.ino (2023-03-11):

/*  2015 / 2016 / 2017
 *  Morse decoder for Attiny85 and the #AttinyArcade by Andy Jackson (M0RCL) - Twitter @andyhighnumber
 *   
 *  Displays morse code coming in on the assigned pin in real time, via a 5-line scrolling display 
 *   
 *  Inspired by, and designed to run on the Attiny Arcade hardware. Check out www.webboggles.com for info on this hardware.
 *   
 *  When running, use:
 *   - The right button to send morse
 *   - The left button to start and stop the software running
 *   
 *  Any code not covered by the licences below can be used freely with attribution. No warranties whatsoever are provided or implied.
 *   
 *  ****************************************************************************************************
 *  * The core morse decoder here is a slightly modified version of WB7FHC's Morse Code Decoder v. 1.1 *
 *  * (c) 2014, Budd Churchward - WB7FHC                                                               *
 *  * This is an Open Source Project                                                                   *
 *  * http://opensource.org/licenses/MIT                                                               *
 *  * Search YouTube for 'WB7FHC' to see several videos of this project as it was developed.           *
 *  * Also see https://github.com/kareiva/wb7fhc-cw-decoder                                            *
 *  ****************************************************************************************************
 *  
 *  This sketch is using the screen control and font functions written by Neven Boyanov for the http://tinusaur.wordpress.com/ project
 *  Source code and font files available at: https://bitbucket.org/tinusaur/ssd1306xled
 * 
 *  Sleep code is based on this blog post by Matthew Little:
 *  http://www.re-innovation.co.uk/web12/index.php/en/blog-75/306-sleep-modes-on-attiny85
 */
 
#include <EEPROM.h>
#include "font6x8AJ.h"
#include <avr/pgmspace.h>
#include <avr/sleep.h>
#include <avr/interrupt.h> // needed for the additional interrupt

#define DIGITAL_WRITE_HIGH(PORT) PORTB |= (1 << PORT)
#define DIGITAL_WRITE_LOW(PORT) PORTB &= ~(1 << PORT)

// Routines to set and clear bits (used in the sleep code)
#define cbi(sfr, bit) (_SFR_BYTE(sfr) &= ~_BV(bit))
#define sbi(sfr, bit) (_SFR_BYTE(sfr) |= _BV(bit))

// Defines for OLED output
#define SSD1306XLED_H
#define SSD1306_SCL   PORTB4  // SCL, Pin 4 on SSD1306 Board - for webbogles board
#define SSD1306_SDA   PORTB3  // SDA, Pin 3 on SSD1306 Board - for webbogles board
#define SSD1306_SA    0x78  // Slave address

#define FIRSTLINE 2     // The first displayed line of decoded morse on the LCD
#define LASTLINE 6      // The last displayed line of decoded morse on the LCD
#define LINELENGTH 20   // The number of characters on one completed line
#define MAXWORD 17      // The longest any single word can be (needed to manage buffer limits)

// Drawing functions - adapted from those at https://bitbucket.org/tinusaur/ssd1306xled
void ssd1306_init(void);
void ssd1306_xfer_start(void);
void ssd1306_xfer_stop(void);
void ssd1306_send_byte(uint8_t byte);
void ssd1306_send_command(uint8_t command);
void ssd1306_send_data_start(void);
void ssd1306_send_data_stop(void);
void ssd1306_setpos(uint8_t x, uint8_t y);
void ssd1306_fillscreen(uint8_t fill_Data);
void ssd1306_char_f6x8(uint8_t x, uint8_t y, char ch[]);
void ssd1306_draw_bmp(uint8_t x0, uint8_t y0, uint8_t x1, uint8_t y1, uint8_t bitmap[]);

// Custom draw functions - allow for extra functionality like inverse display
void sendBlock(byte, bool);
void sendByte(byte, bool);

int stopRunning = 0;

// Other generic functions (both originated in code from webboggles.com and the sleep code is by Matthew Little - see above)
void beep(int,int);
void system_sleep(void);
void doNumber (int,int,int);

// Specific main function to decode morse
void decodeMorse(void);

// Variable declarations for decoder
int inputPin = 2;         // input data comes in here (key or decoder)
int audio = 1;            // will store the value we read on this pin
boolean mute = 0;         // Mute the speaker
int letterCount = 0;
int LCDline = FIRSTLINE;          // keeps track of which line we're printing on
boolean ditOrDah = true;  // We have either a full dit or a full dah
int dit;            

// The following values will auto adjust to the sender's speed
int averageDah;                   // A dah should be 3 times as long as a dit
int averageWordGap;               // will auto adjust

boolean characterDone = true; // A full character has been sent

int downTime = 0;        // How long the tone was on in milliseconds
int upTime = 0;          // How long the tone was off in milliseconds
int myBounce = 2;        // Used as a short delay between key up and down
long startDownTime = 0;  // Arduino's internal timer when tone first comes on
long startUpTime = 0;    // Arduino's internal timer when tone first goes off

int currentWordLength = 0;
int currentWordPos = 0;
char currentWord[MAXWORD];
char screenText[LASTLINE-FIRSTLINE+1][LINELENGTH+1];
int lastWordLength = 0;

boolean justDid = true; // Makes sure we only print one space during long gaps

int myNum = 0;           // We will turn dits and dahs into a binary number stored here
char mySet[] ="##TEMNAIOGKDWRUS##QZYCXBJP#L#FVH09#8###7#####/-61#######2###3#45";
char decodedCharacter = ' ';       // We will store the actual character decoded here

// Interrupt handlers
ISR(PCINT0_vect){ // PB0 pin button interrupt           
  stopRunning = 1; // stop the programme :)
}

void playerIncMorse(){ // PB2 pin button interrupt
}


// Arduino stuff - setup
void setup() {
  DDRB = 0b00000010;    // set PB1 as output (for the speaker)
  PCMSK = 0b00000001; // pin change mask: listen to portb bit 1
  GIMSK |= 0b00100000;  // enable PCINT interrupt 
  sei();          // enable all interrupts
}
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

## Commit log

2022-09-16 First commit of tiny handheld
    [Tiny handheld.kicad_pcb, Tiny handheld.kicad_sch]
2022-09-16 designed custom 5 way button and finished up footprint assignment
    [Tiny handheld.kicad_sch]
2022-09-16 removed errors (ERC)
    Left warnings in
    [Tiny handheld.kicad_sch]
2022-09-16 added missing button footprint
    [Tiny handheld.kicad_sch]
2022-09-16 updated usb c port schematic
    [Tiny handheld.kicad_sch]
2022-09-16 updated footprint on attiny 85 and removed backup zip files
    [Tiny handheld.kicad_pcb, Tiny handheld.kicad_sch]
2022-09-16 fixed footprint error U2
    Changed the values back to the original
    [Tiny handheld.kicad_pcb, Tiny handheld.kicad_sch]
2022-09-16 added different switch in schematic
    [Tiny handheld.kicad_sch]
2022-09-16 fixed ERC error
    [Tiny handheld.kicad_sch]
2022-09-16 changed switch for audio toggle
    [Tiny handheld.kicad_sch]
2022-09-16 removed all errors from pcb new
    Ready to start pcb design
    [Tiny handheld.kicad_pcb]
2022-09-16 changed speaker footprint and updated it
    [Tiny handheld.kicad_pcb, Tiny handheld.kicad_sch]
2022-09-16 first layout tryout
    [Tiny handheld.kicad_pcb, Tiny handheld.kicad_sch]
2022-09-16 layout improved
    [Tiny handheld.kicad_pcb]
2022-09-16 improved layout and added silkscreen
    [Tiny handheld.kicad_pcb]
2022-09-17 updated schematic (nothing special)
    [Tiny handheld.kicad_pcb, Tiny handheld.kicad_sch]
2022-09-17 removed vertical screen header
    [Tiny handheld.kicad_sch]
2022-09-17 started routing
    [Tiny handheld.kicad_pcb]
2022-09-17 continued wiring
    [Tiny handheld.kicad_pcb]
2022-09-17 more connections made
    [Tiny handheld.kicad_pcb]
2022-09-17 all errors (that i found critical) resolved
    [Tiny handheld.kicad_pcb]
2022-09-17 board cleanup
    [Tiny handheld.kicad_pcb]
2022-09-17 first melted circuit tryout (rounded tracks)
    [Tiny handheld.kicad_pcb, Tiny handheld.kicad_sch]
2022-09-17 removed fluid traces, First functional design
    [Tiny handheld.kicad_pcb]
2022-09-17 V1.0
    Added silkscreen and finished up with straight lines (no curves yet)
    [Tiny handheld.kicad_pcb]
2022-09-17 Added curvy wires
    Because they are the best thing in this straight world
    [Tiny handheld.kicad_pcb]
2022-09-17 updated page settings (kicad)
    [Tiny handheld.kicad_pcb]
2022-09-17 gerber files added
    [Tiny handheld-B_Cu.gbr, Tiny handheld-B_Mask.gbr, Tiny handheld-B_Paste.gbr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]
2022-09-17 New gerber files
    [Tiny handheld-B_Cu.gbr, Tiny handheld-B_Mask.gbr, Tiny handheld-B_Paste.gbr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]
2022-09-17 Fixed gerber files
    can be uploaded directly to easyeda
    [Tiny handheld-B_Cu.gbr, Tiny handheld-B_Mask.gbr, Tiny handheld-B_Paste.gbr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]
2022-10-06 Start on V2.0
    V1.0 could not be programmed easily via usb C, which was the whole point.
    Going back to arduino ISP programmer.
    [Tiny handheld.kicad_sch]
2022-10-06 New layout and silkscreen improvements
    [Tiny handheld.kicad_pcb, Tiny handheld.kicad_sch]
2022-10-06 finished silkscreen and component layout
    [Tiny handheld.kicad_pcb]
2022-10-06 fixed screen orientation
    [Tiny handheld.kicad_pcb]
2022-10-06 fixed screen orientation again
    [Tiny handheld.kicad_pcb]
2022-10-06 added power testpoints
    [Tiny handheld.kicad_pcb, Tiny handheld.kicad_sch]
2022-10-06 Start Routing
    [Tiny handheld.kicad_pcb, Tiny handheld.kicad_sch]
2022-10-07 enh pcb layout and silkscreen
    [Tiny handheld.kicad_pcb, Tiny handheld.kicad_sch]
2022-10-08 started routing new PCB
    [Tiny handheld.kicad_pcb]
2022-10-08 enh silkscreen
    [Tiny handheld.kicad_pcb]
2022-10-08 wiring part 1
    [Tiny handheld.kicad_pcb]
2022-10-08 completed routing, started erc
    [Tiny handheld.kicad_pcb]
2022-10-08 ERC finished (with some exclusions)
    [Tiny handheld.kicad_pcb]
2022-10-08 V2.0 Finished
    [Tiny handheld.kicad_pcb, Tiny handheld.kicad_sch]
2022-10-08 fames rounded tracks added
    added bom
    [Tiny handheld.kicad_pcb]
2022-10-08 enh tracks
    [Tiny handheld.kicad_pcb]
2022-10-10 Added V1.0 and v2.0 seperately
    [Tiny handheld.kicad_pcb, Tiny handheld.kicad_sch, bom.csv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]
2022-10-31 started on V2.1, Fixed 5w-joystick
    [Tiny handheld.kicad_pcb, Tiny handheld.kicad_sch, bom.csv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]
2022-10-31 stopped for now.
    [Tiny handheld.kicad_pcb]
2022-11-21 enh v2.1
    - new 5 way button footprint (functional)
    - larger keyhole
    - rewired
    [Tiny handheld.kicad_pcb, Tiny handheld.kicad_sch, bom.csv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]
2022-11-21 Improved silkscreen
    [Tiny handheld.kicad_pcb]
2022-11-21 improved silkscreen and archieved 3d models
    [Tiny handheld.kicad_pcb, Tiny handheld.kicad_sch]
2022-11-21 Improved wiring spacing
    [Tiny handheld.kicad_pcb, Tiny handheld.kicad_sch]
2022-11-21 Created smooth traces version of V2.1
    [Tiny handheld.kicad_pcb]
2022-11-28 small improvements V2.1
    [Tiny handheld.kicad_pcb, bom.csv, designators.csv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]
2022-12-04 V2.2 started (minor bug fixes)
    [Tiny handheld.kicad_pcb]
2022-12-05 Fixed Silkscreen error
    [Tiny handheld.kicad_pcb]
2022-12-05 added JY JX and JC to schematic
    [Tiny handheld.kicad_pcb, Tiny handheld.kicad_sch]
2023-03-11 Added games and potential oled driver
    Oled drivers need to be implemented
    [Tiny handheld.kicad_pcb]
